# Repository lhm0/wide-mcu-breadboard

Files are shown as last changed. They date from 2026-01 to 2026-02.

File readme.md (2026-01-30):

# Fixing Breadboards for Wide Microcontrollers – Pico & ESP32 Edition

### Update 30.01.2026: added 3mf files for Arduino nano. There is a version with colored red and black lines next to the power rails (Arduino nano board only).

### Update 27.01.2026: breadboard for Arduino nano added. 

### Update 27.01.2026: breadboard for 900 mil ESP32 added. Renamed the STL files in order to avoid confusion, added .jpg files which correspond to the .stl files. Added model guide, which presents all available versions.

### Update 25.01.2026: test_print.stl added. This is a quick print of the breadboard's main feature. If your printer can handle this, it can also print the full breadboard.

### Update 22.01.2026: more variants included (photos to come), nozzle size included in readme.md

This project provides a custom 3D-printed breadboard body designed to accommodate modern, wide microcontroller development boards such as the **Raspberry Pi Pico**, **ESP32 Dev Board**, and **Arduino nano**. The metal spring contacts from a standard commercial breadboard are removed and reused inside the new housing, giving you a full-size 63×5 contact area and two power rails — just like the real thing.

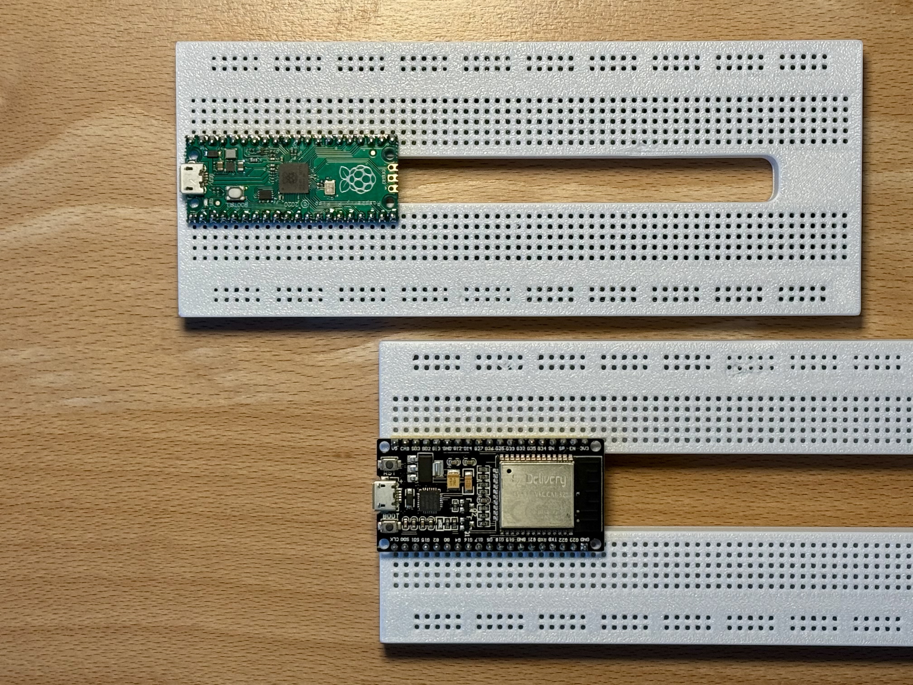
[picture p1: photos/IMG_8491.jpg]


## ✨ Why?

Many modern µC boards are too wide for typical solderless breadboards:

- With a **Raspberry Pi Pico**, only two holes per pin remain usable.
- With an **ESP32 Dev Board**, no holes remain at all — you need two breadboards side by side.

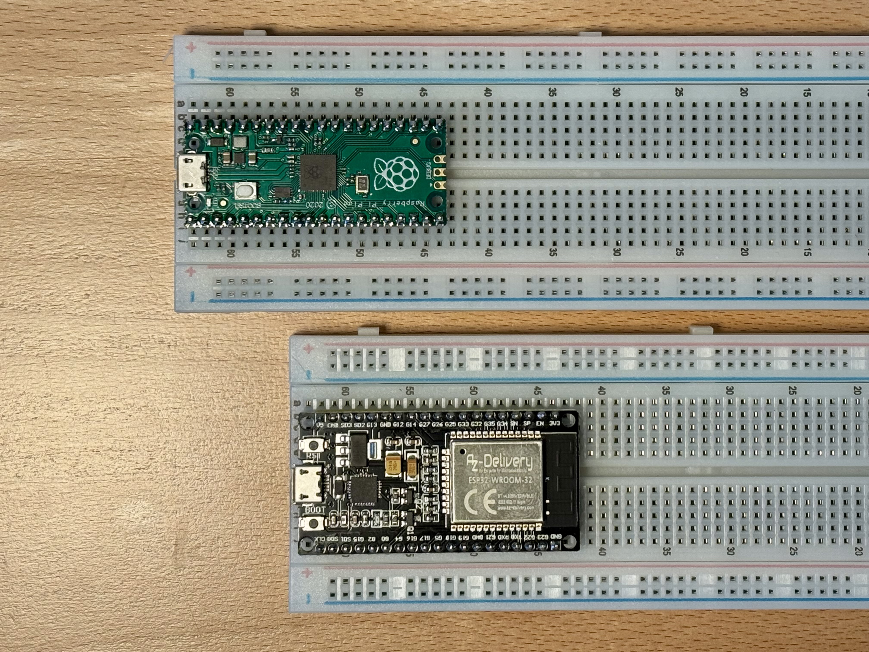
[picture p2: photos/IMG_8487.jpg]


With this custom breadboard, the microcontroller sits in the middle, leaving **four free holes per pin** for jumper wires and components — ideal for prototyping.

## 📦 Features

- Full 63×5 breadboard layout
- Two vertical power rails (left & right)
- Contact springs **recycled** from an existing breadboard
- Six variants:
  - **Pico version 1:** 7×2.54 mm pin spacing (17.78 mm)
  - **Pico version 2:** pin spacing split: 24 rows with 17.78 mm spacing (corresponds to RP pico), 39 rows with 7.62 mm spacing (correponds to DIL ICs)
  - **ESP32 version 1:** 10×2.54 mm pin spacing (25.40 mm)
  - **ESP32 version 2:** pin spacing split: 2 columns with 25.40 mm spacing, 3 columns with 7.62 mm spacing
  - **ESP32 version 3:** pin spacing split: 2 columns with 25.40 mm spacing, 2 columns with 7.62 mm spacing
  - **Arduino nano version 1:** 6*2.54 mm pin spacing (15.24 mm)
- Optional screw-mounted bottom plate
- Fully 3D-printable design (Fusion 360 source included)

## 📁 Included Files

This repository contains:

- /ESP32dev/          – Source CAD file, STL model, 3MF file for ESP32 development board
- /RaspberryPiPico/   – Source CAD file, STL model, 3MF file for Raspberry Pi Pico
- /photos/            – Build & assembly photos (for documentation)
- readme.md           - this file
- license.txt         - license

## 🖨 Printing Notes

- Material: **PLA** works well (ABS/ASA for heat resistance)
- Layer height: 0.2 mm recommended
- **nozzle diameter: 0.4 mm recommended**
- Infill: 50%
- Supports: Not required for main board
- Optional: Pause print to insert M2 nuts for screw mounting

Alternatively, the bottom plate may be **glued** instead of screwed.

## 🛠 Assembly Overview

1. Remove bottom adhesive tape from a commercial breadboard
2. Extract the metal spring contacts (keep power rails separate)
3. Insert contacts into the 3D-printed body
4. Insert power rails on both sides
5. Mount or glue the bottom plate
6. Plug in Pico or ESP32 and start prototyping!

## 📷 Photos & Documentation

See the Instructables article for full build documentation and photos:  
*link coming soon*

## 📝 Inspiration & Credits

The concept was inspired by the MAKE Advent Calendar project on Tinkercad:  
[MAKE ESP Breadboard](https://www.tinkercad.com/things/bsXsvygyo6F-make-esp-breadboard)
This version expands the idea to a **full-length 63-row breadboard** with **complete power rails**.

## 📜 License
Creative Commons Attribution-NonCommercial-ShareAlike 4.0 (CC BY-NC-SA 4.0)
see license.txt

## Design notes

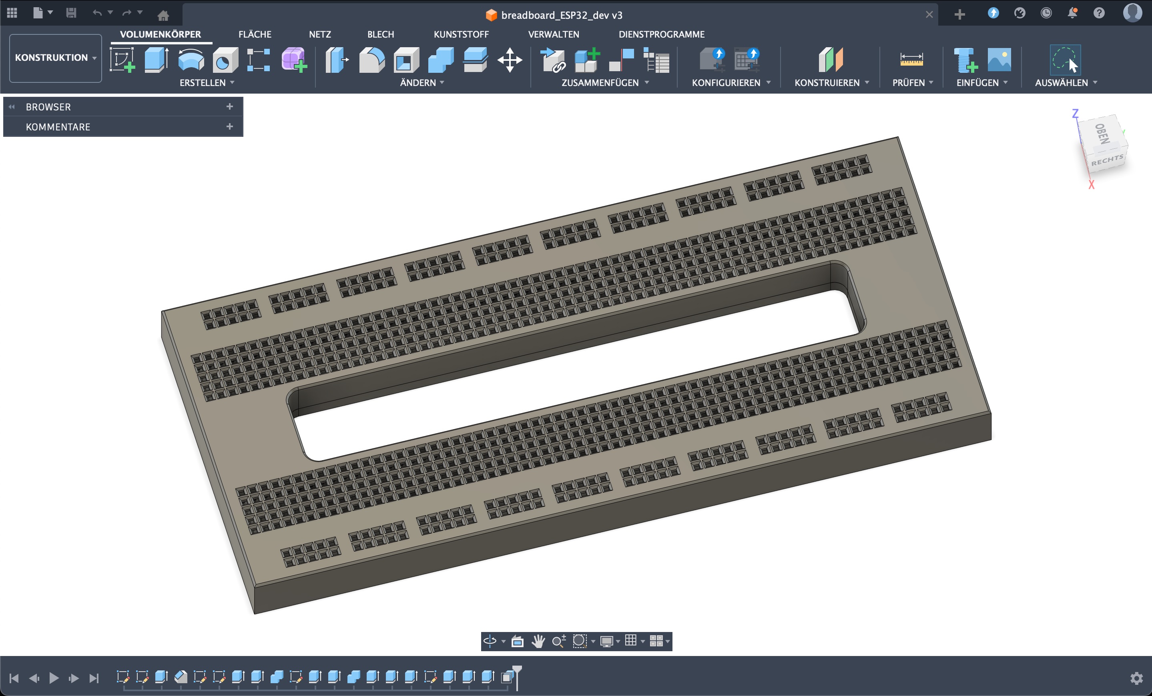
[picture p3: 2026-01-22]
photos/rendering_ESP32dev.jpg

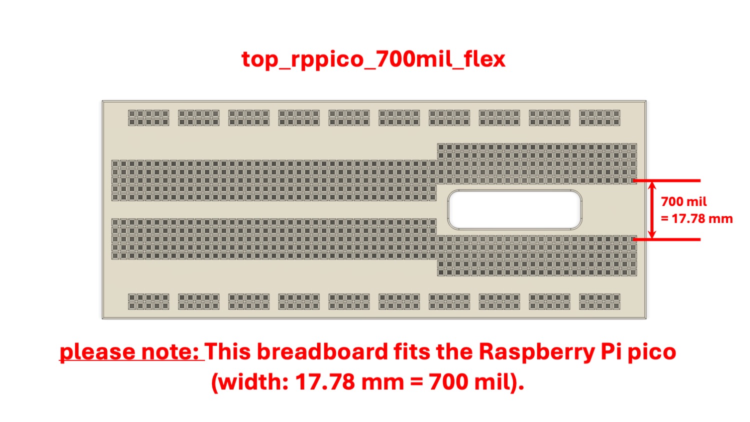
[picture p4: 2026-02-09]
photos/version6.jpeg

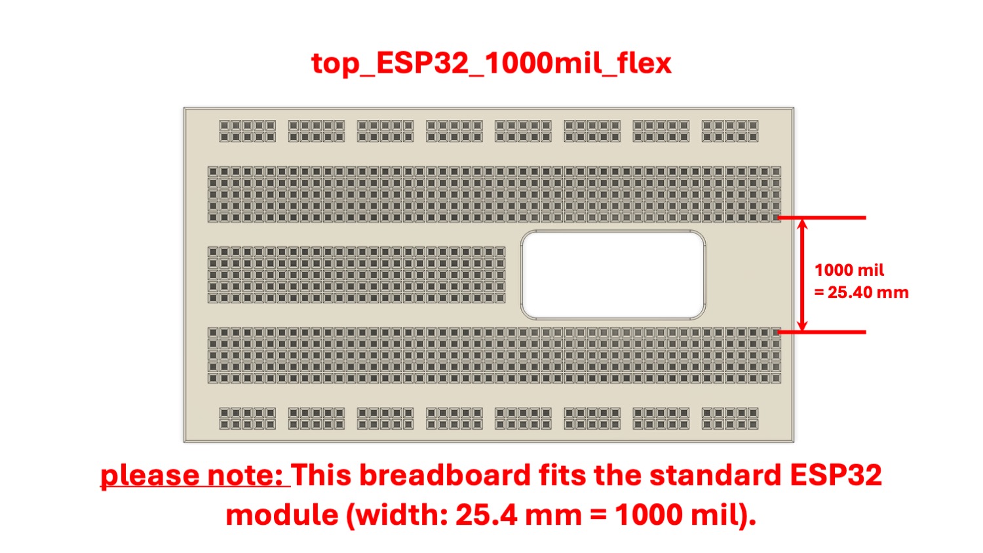
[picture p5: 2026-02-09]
photos/version2.jpeg

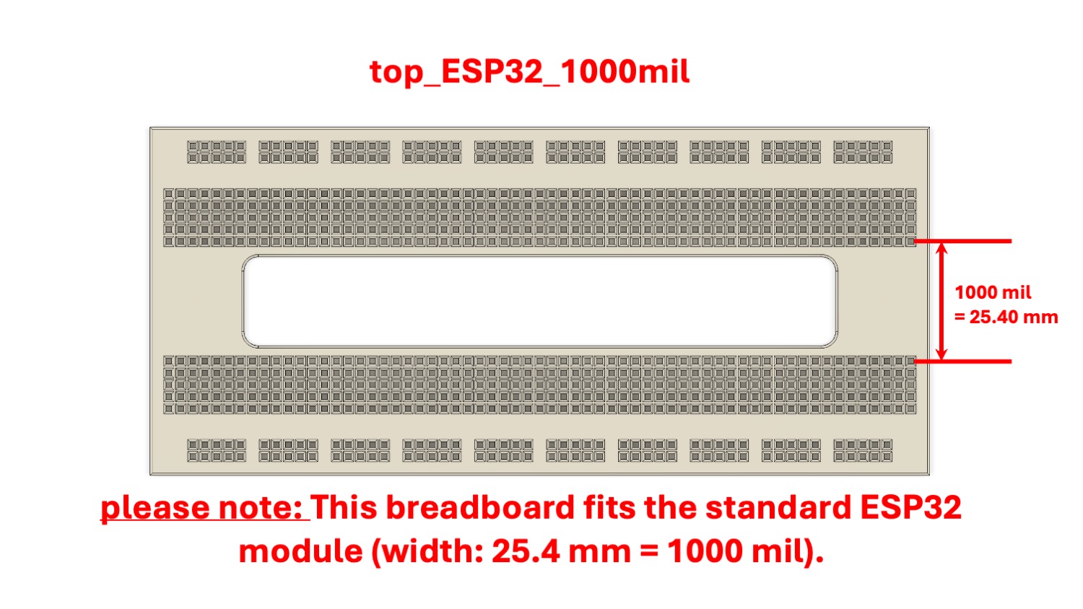
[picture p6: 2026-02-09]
photos/version1.jpeg

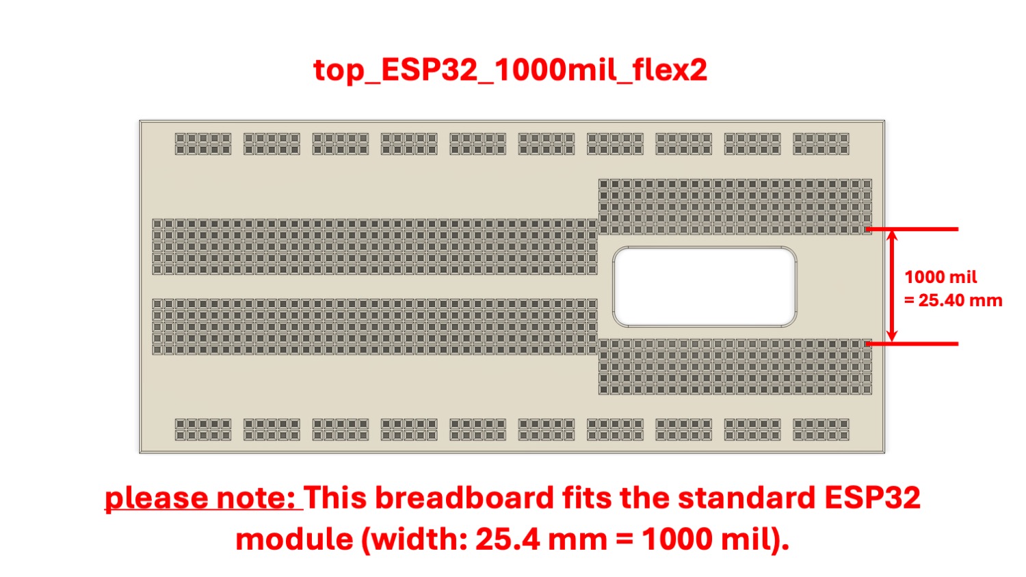
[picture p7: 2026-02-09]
photos/version3.jpeg

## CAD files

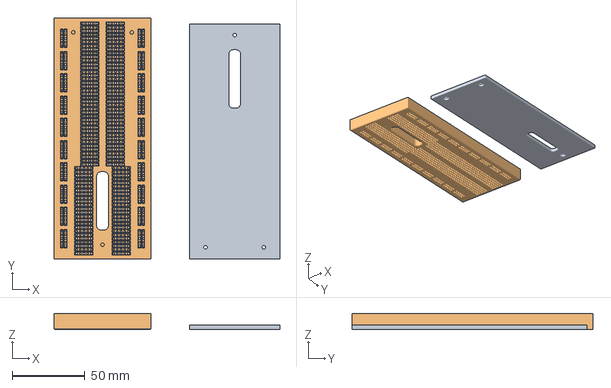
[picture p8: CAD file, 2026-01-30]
ArduinoNano/Arduino_nano_600mil_flex2.3mf
154.9 x 165.5 x 11.0 mm
bottom_Arduino_nano_600mil_flex2.stl
top_Arduino_nano_600mil_flex2.stl

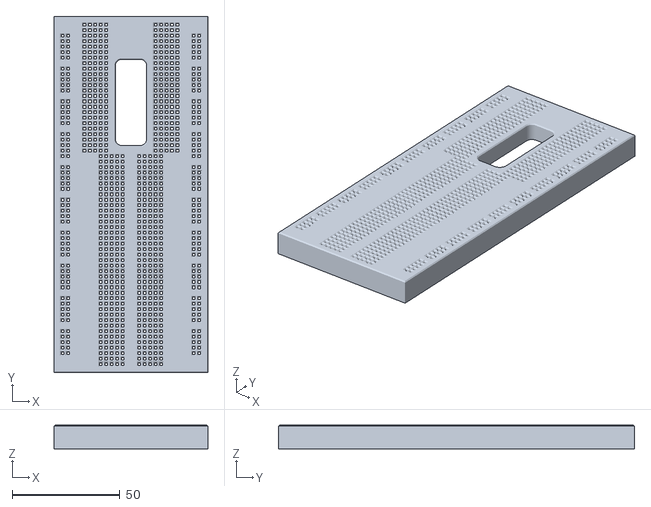
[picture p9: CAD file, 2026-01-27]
ESP32dev/top_ESP32_900mil_flex2.stl
71.5 x 165.5 x 11.0

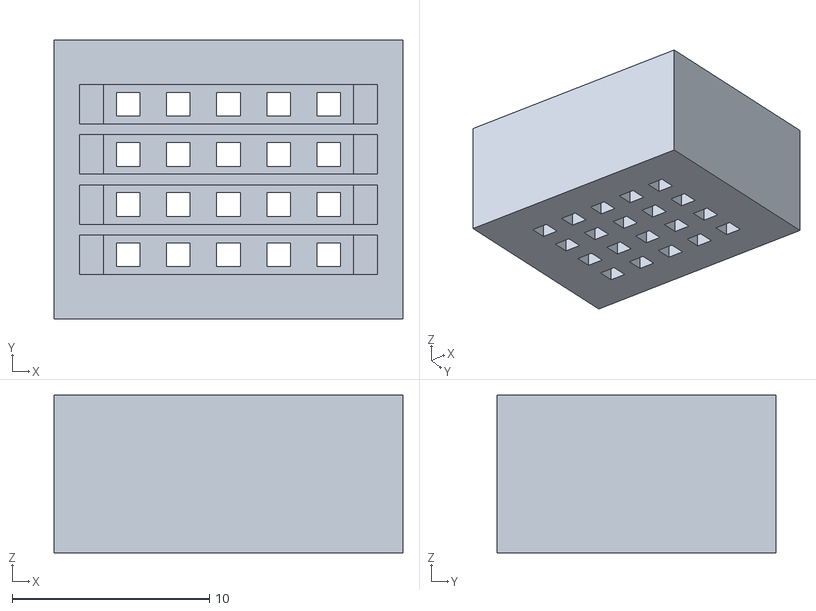
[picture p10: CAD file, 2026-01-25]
test_print/test_print.stl
17.7 x 14.2 x 8.00

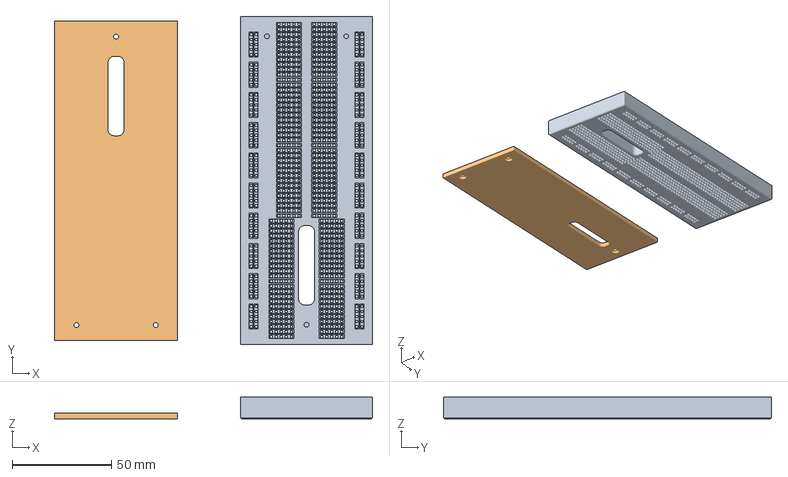
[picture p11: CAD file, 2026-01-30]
ArduinoNano/Arduino_nano_600mil_flex2_color.3mf
160.4 x 165.5 x 11.0 mm
top_Arsuino_nano_600mil_flex2_c
bottom_Arduino_nano_600mil_flex2.stl

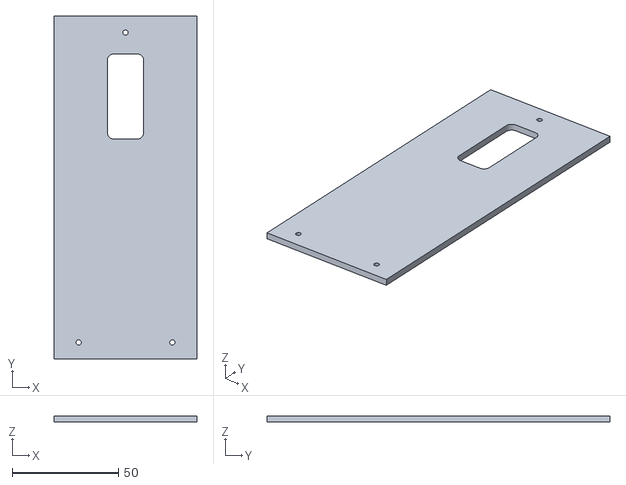
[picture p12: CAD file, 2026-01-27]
ESP32dev/bottom_ESP32_900mil_flex2.stl
67.1 x 161.1 x 3.00

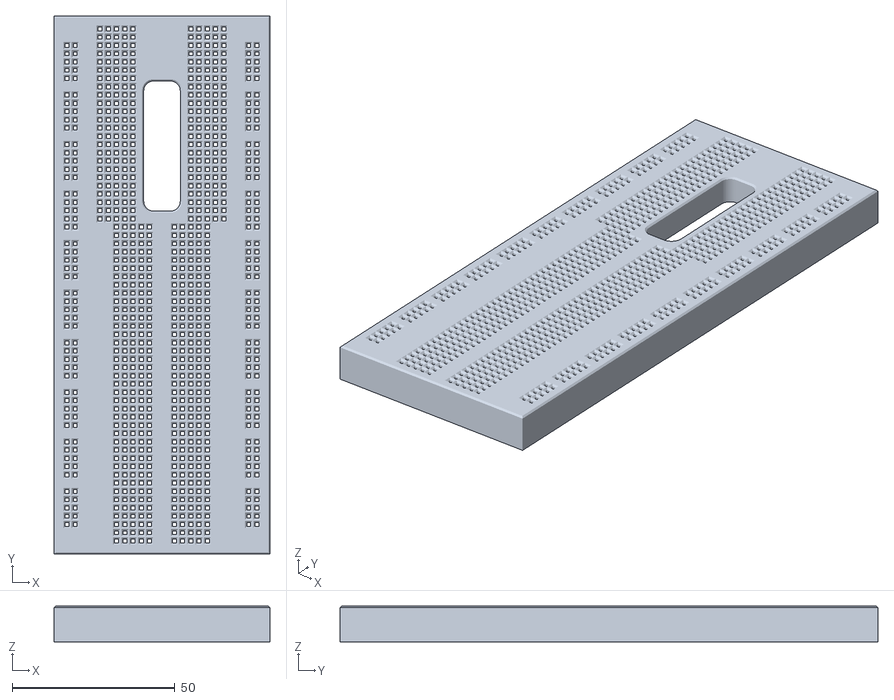
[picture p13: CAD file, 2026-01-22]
RaspberryPiPico/top_rppico_700mil_flex.stl
66.4 x 165.5 x 11.0

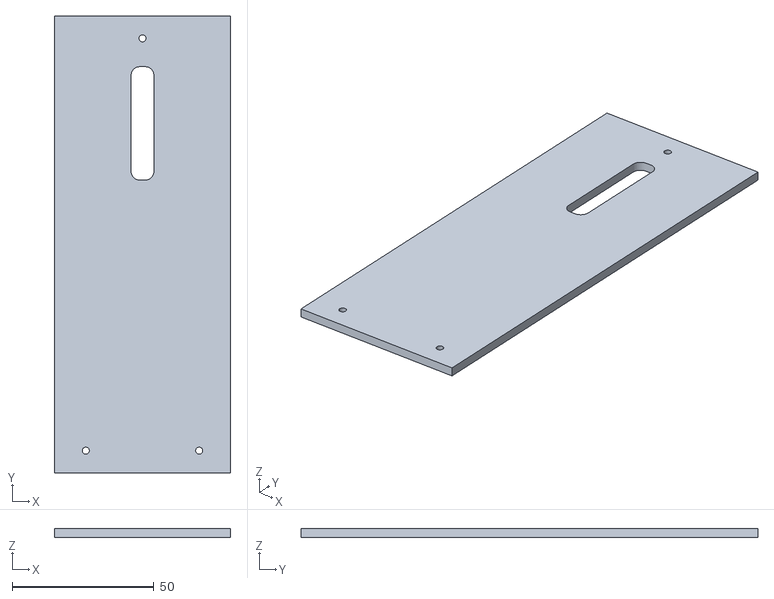
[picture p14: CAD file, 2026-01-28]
ArduinoNano/bottom_Arduino_nano_600mil_flex2.stl
62.1 x 161.1 x 3.00

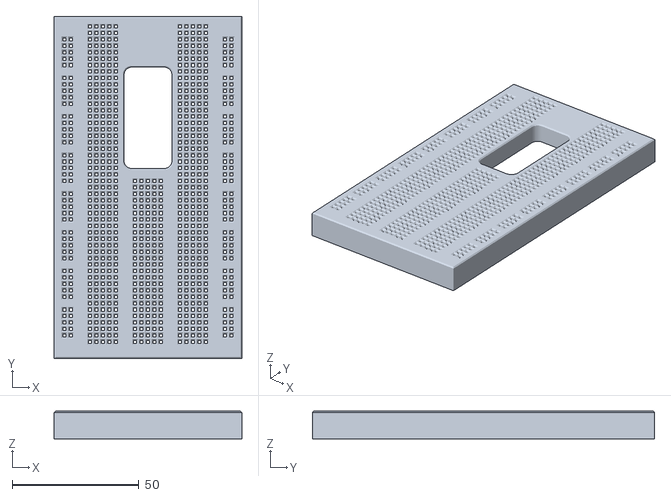
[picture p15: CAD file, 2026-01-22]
ESP32dev/top_ESP32_1000mil_flex.stl
74.0 x 135.0 x 11.0

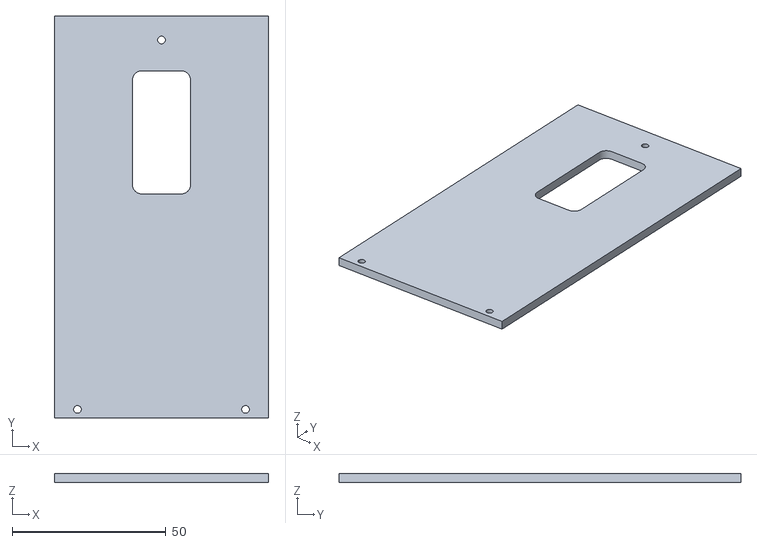
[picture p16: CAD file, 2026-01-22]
ESP32dev/bottom_ESP32_1000mil_flex.stl
69.6 x 130.6 x 3.00

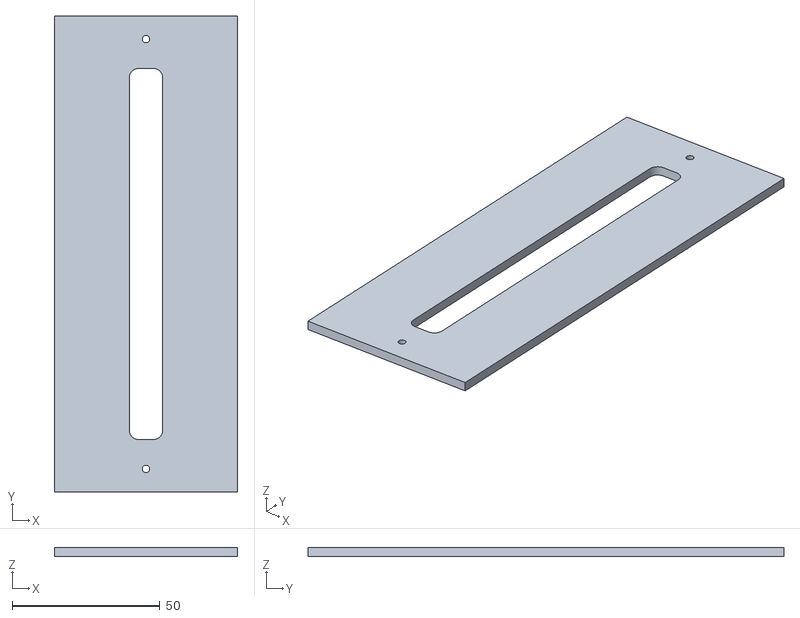
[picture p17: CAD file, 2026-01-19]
RaspberryPiPico/bottom_RPPico_700mil.stl
62.0 x 161.1 x 3.00

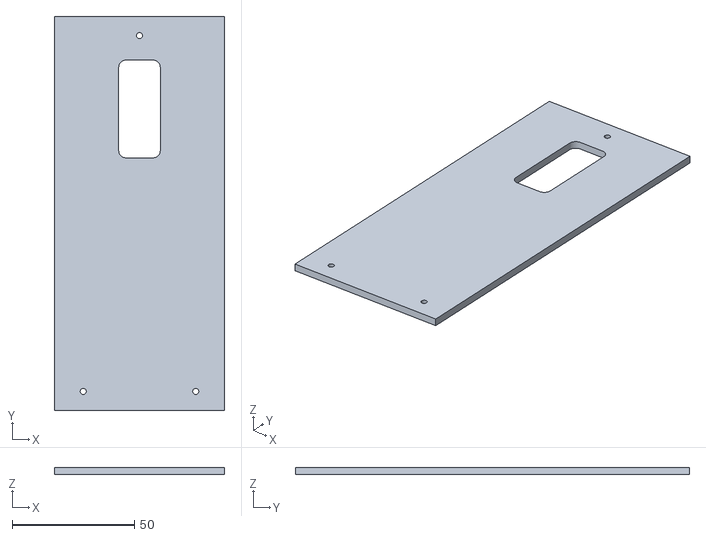
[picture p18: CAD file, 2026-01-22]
ESP32dev/bottom_ESP32_1000mil_flex2.stl
69.6 x 161.1 x 3.00

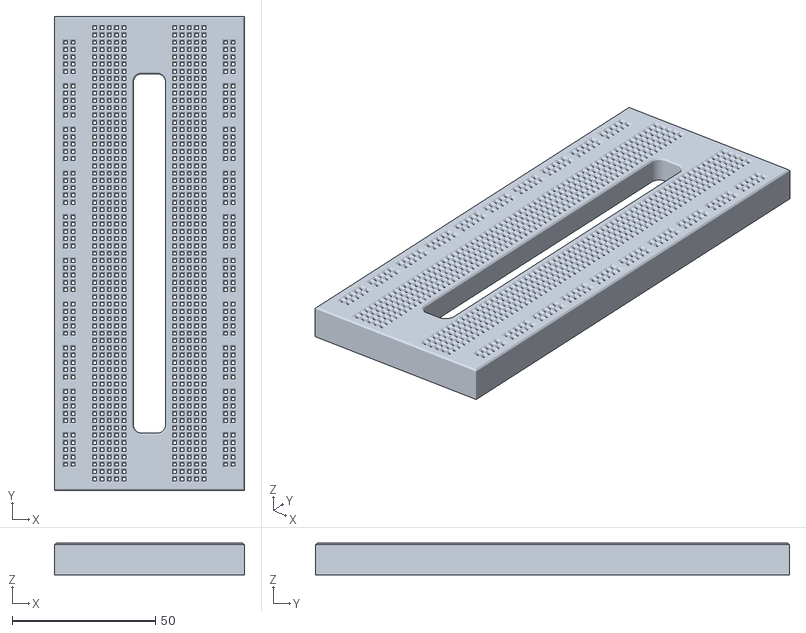
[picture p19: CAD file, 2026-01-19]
RaspberryPiPico/top_RPPico_700mil.stl
66.4 x 165.5 x 11.0

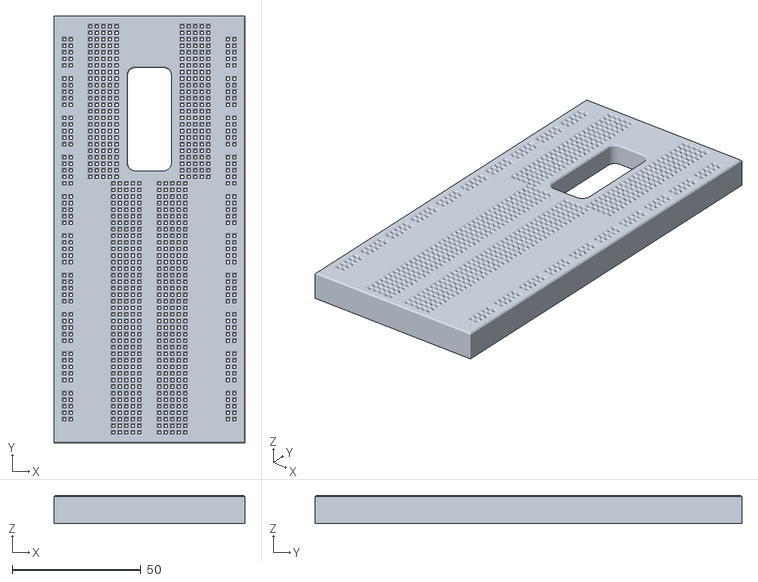
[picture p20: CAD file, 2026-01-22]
ESP32dev/top_ESP32_1000mil_flex2.stl
74.0 x 165.5 x 11.0

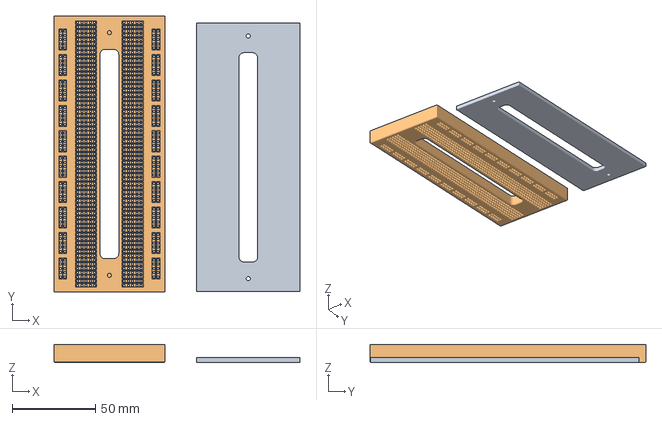
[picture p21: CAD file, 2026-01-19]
RaspberryPiPico/breadboard_rppico_700mil.3mf
147.5 x 165.5 x 11.0 mm
bottom_.stl
top_.stl

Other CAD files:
RaspberryPiPico/breadboard_rppico_700mil_flex.3mf
RaspberryPiPico/bottom_rppico_700mil_flex.stl
ArduinoNano/top_Arduino_nano_600mil_flex2.stl
ESP32dev/breadboard_ESP32_1000mil.3mf
ArduinoNano/breadboard_A_nano_600mil_flex2.f3d
ESP32dev/bottom_ESP32_1000mil.stl
ESP32dev/breadboard_ESP32_1000mil.f3d
ESP32dev/breadboard_ESP32_1000mil_flex.f3d
ESP32dev/breadboard_ESP32_1000mil_flex2.f3d
ESP32dev/breadboard_ESP32_900mil_flex2.f3d
ESP32dev/top_ESP32_1000mil.stl
RaspberryPiPico/breadboard_rppico_700mil.f3d
RaspberryPiPico/breadboard_rppico_700mil_flex.f3d
test_print/test_print.f3d

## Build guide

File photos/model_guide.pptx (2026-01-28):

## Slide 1

top_ESP32_1000mil

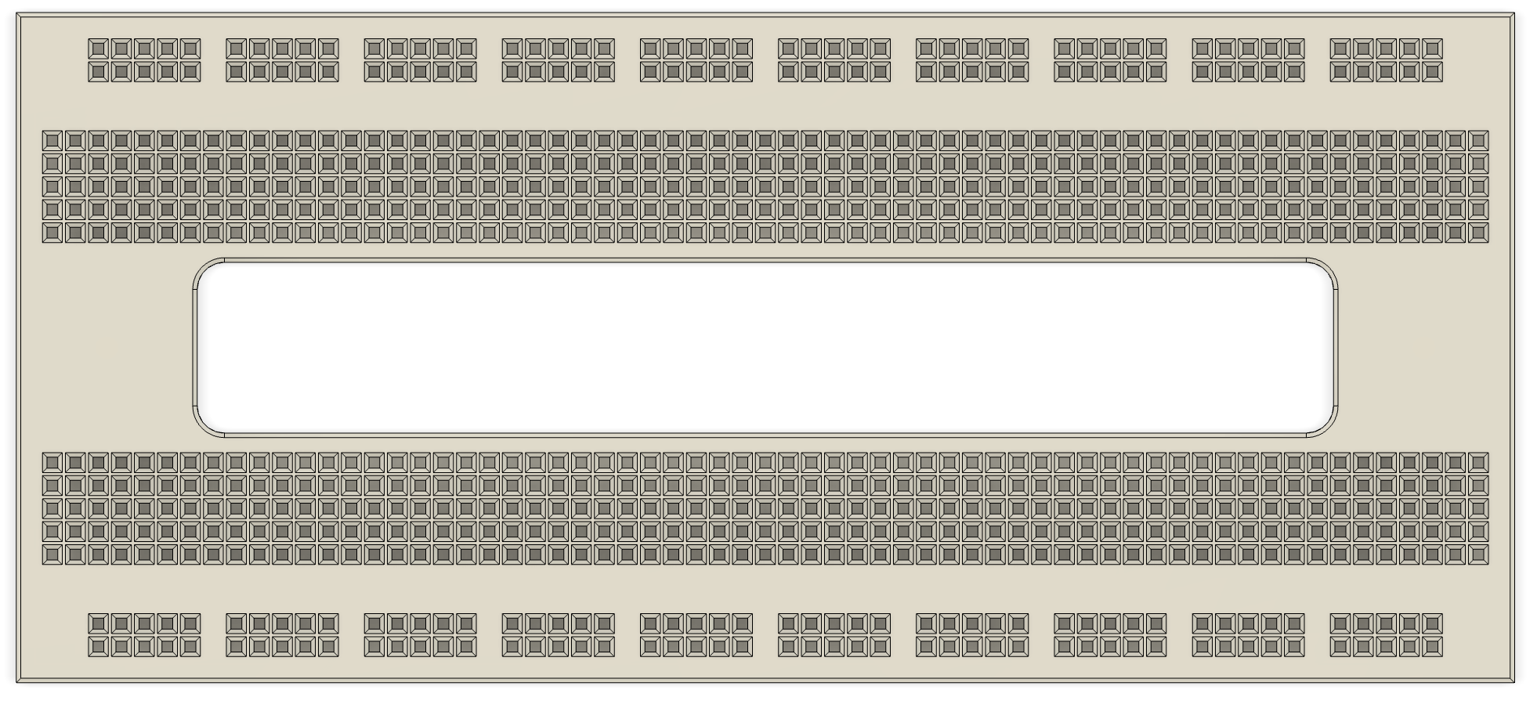
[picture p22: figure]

please note: This breadboard fits the standard ESP32 module (width: 25.4 mm = 1000 mil).

1000 mil
= 25.40 mm

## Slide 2

top_ESP32_1000mil_flex

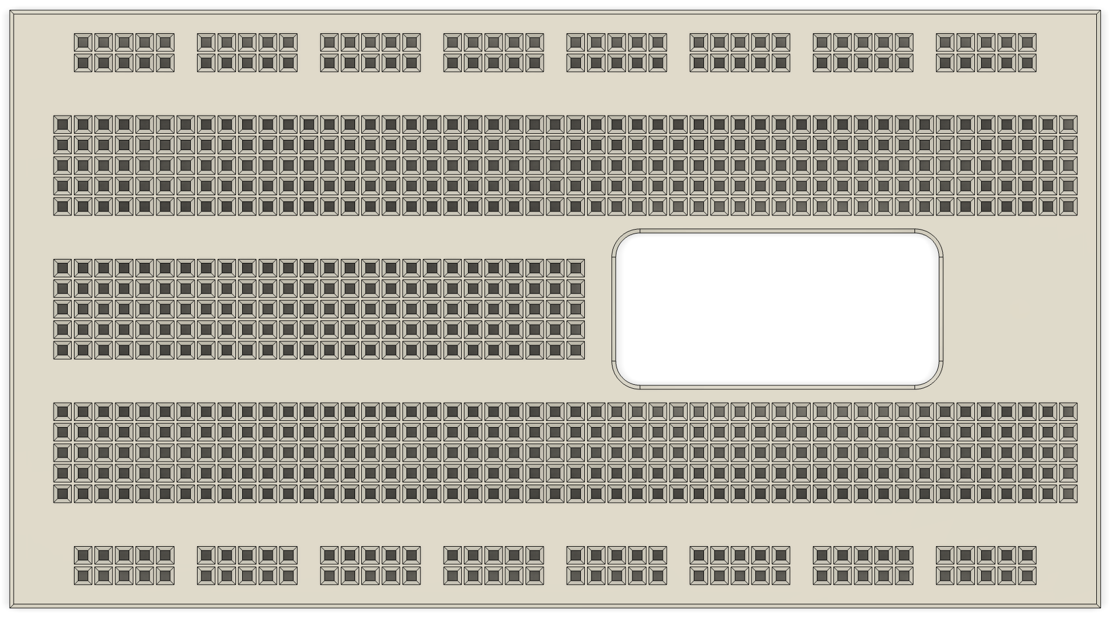
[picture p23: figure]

please note: This breadboard fits the standard ESP32 module (width: 25.4 mm = 1000 mil).

1000 mil
= 25.40 mm

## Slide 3

top_ESP32_1000mil_flex2

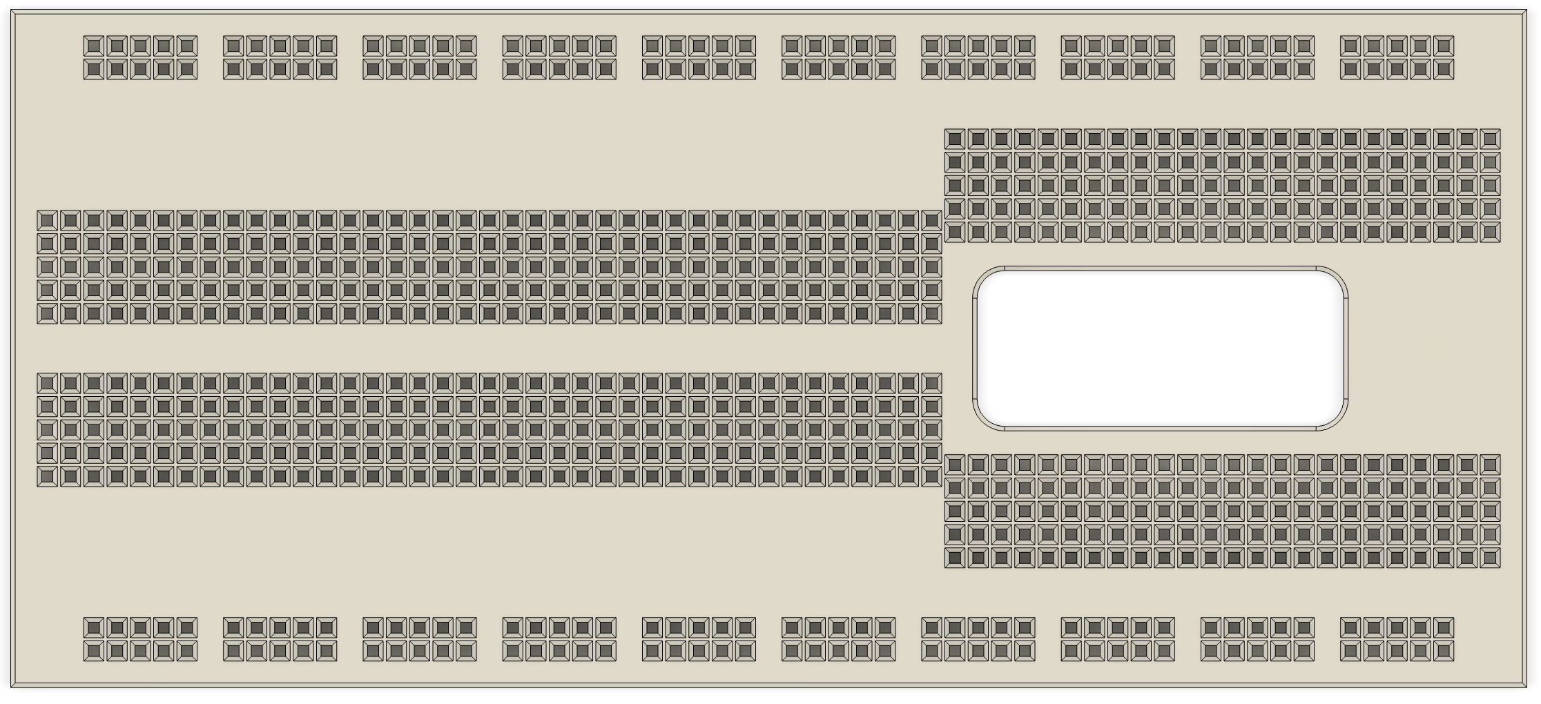
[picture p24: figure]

please note: This breadboard fits the standard ESP32 module (width: 25.4 mm = 1000 mil).

1000 mil
= 25.40 mm

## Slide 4

top_ESP32_900mil_flex2

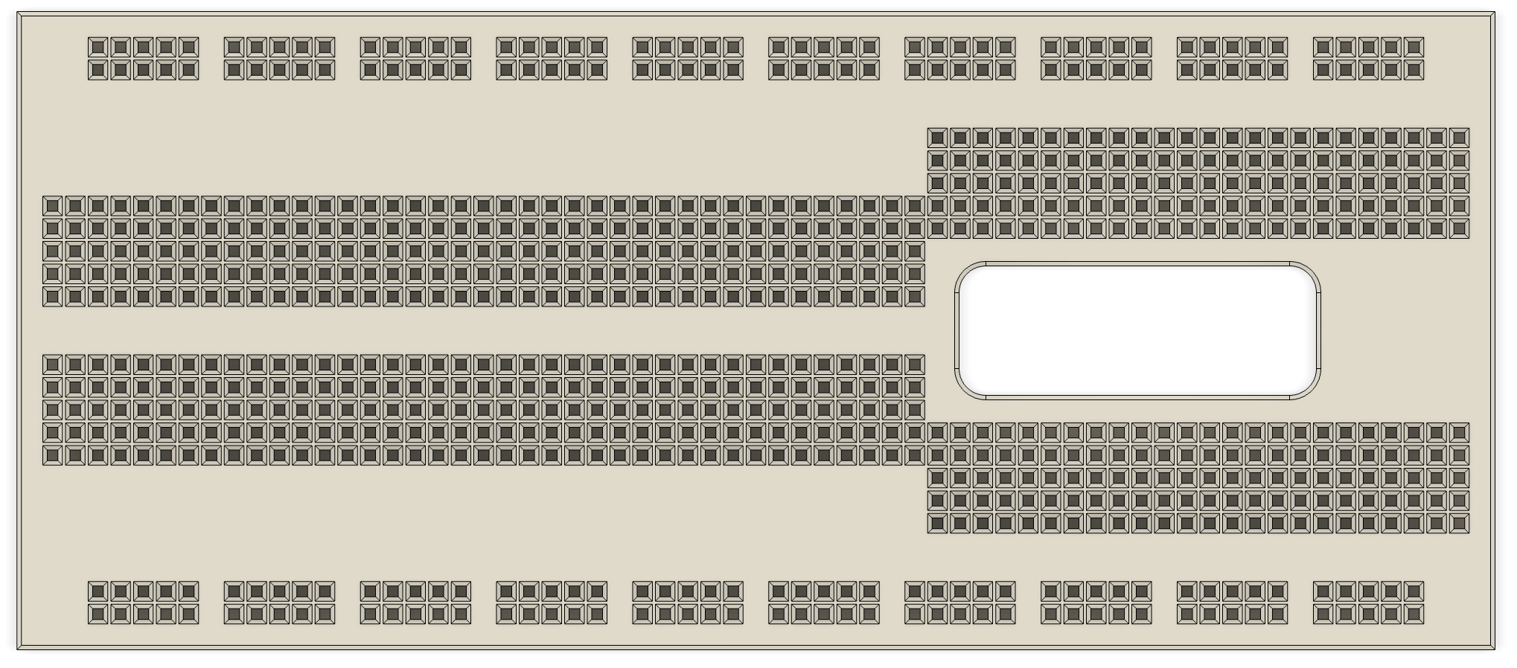
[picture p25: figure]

please note: this breadboard fits a narrow version of
the ESP32 module. Use the 1000 mil files for standard width

900 mil
= 22.86 mm

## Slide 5

top_RPPico_700mil

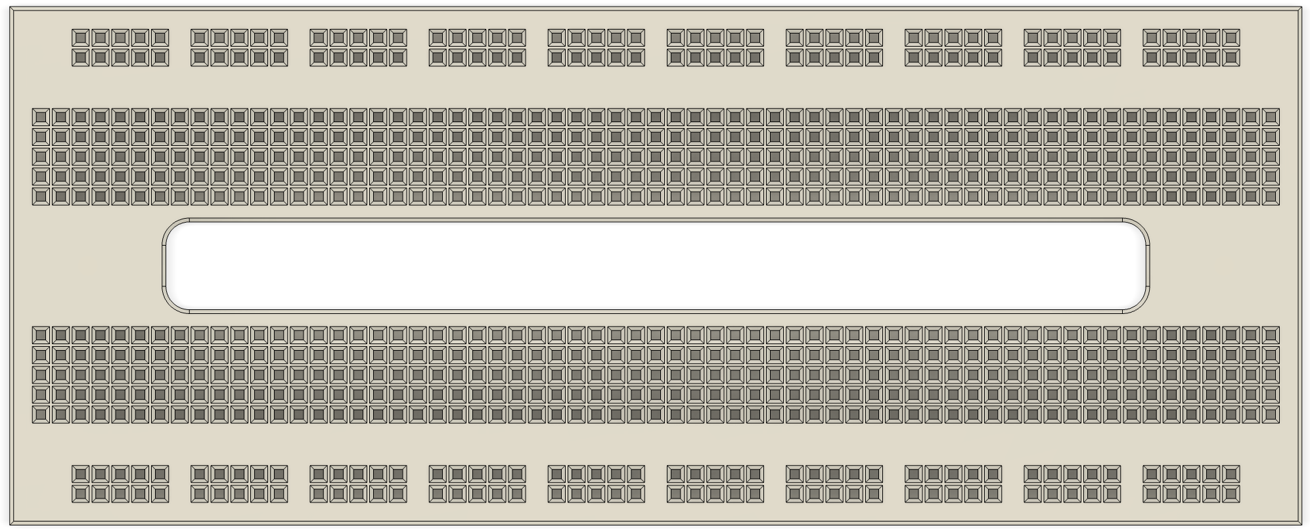
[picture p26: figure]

please note: This breadboard fits the Raspberry Pi pico (width: 17.78 mm = 700 mil).

700 mil
= 17.78 mm

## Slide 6

top_rppico_700mil_flex

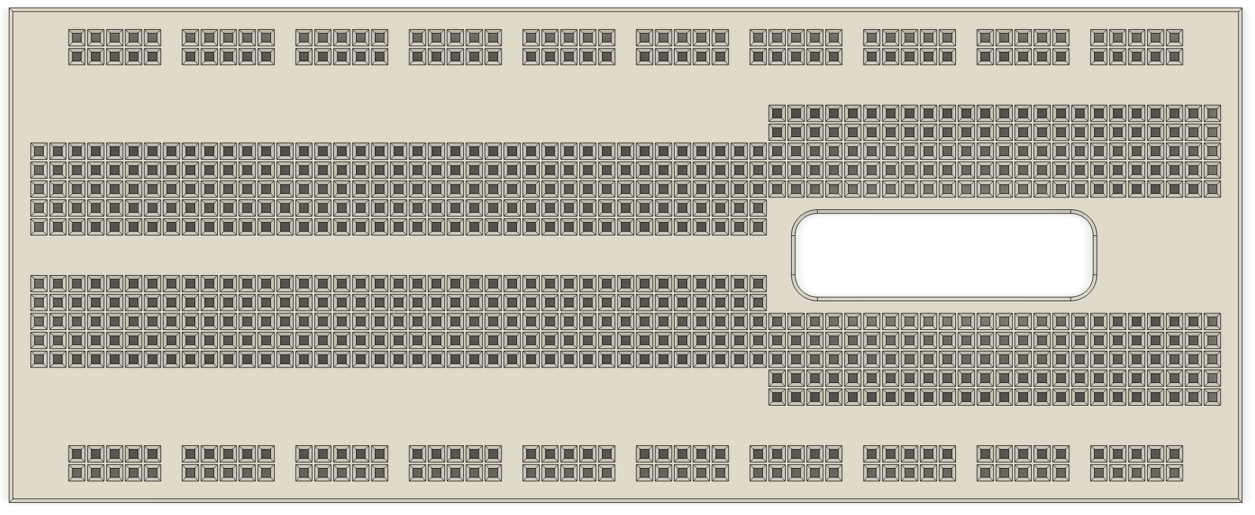
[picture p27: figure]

please note: This breadboard fits the Raspberry Pi pico (width: 17.78 mm = 700 mil).

700 mil
= 17.78 mm

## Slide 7

top_Arduino_nano_600mil_flex2

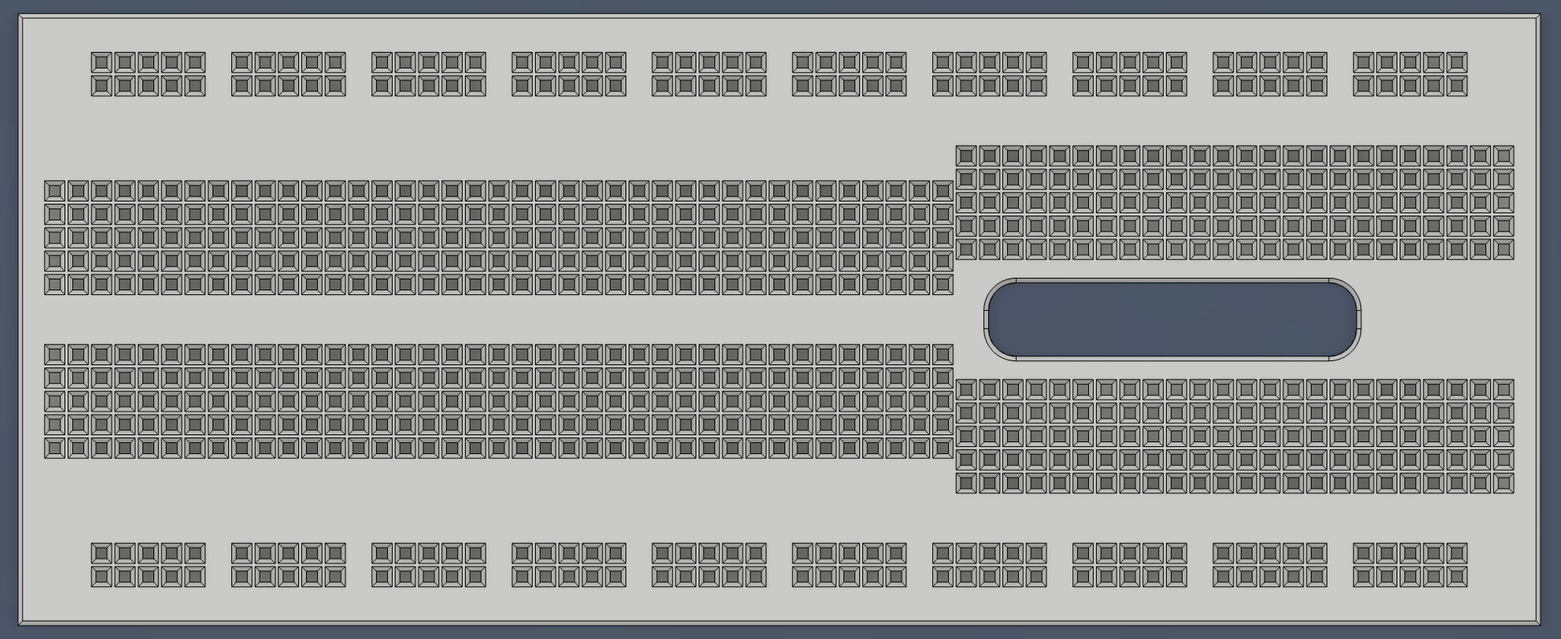
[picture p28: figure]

please note: This breadboard fits the Arduino nano
(width: 15.24 mm = 600 mil).

600 mil
= 15.24 mm

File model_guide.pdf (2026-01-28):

top_ESP32_1000mil

1000 mil
= 25.40 mm

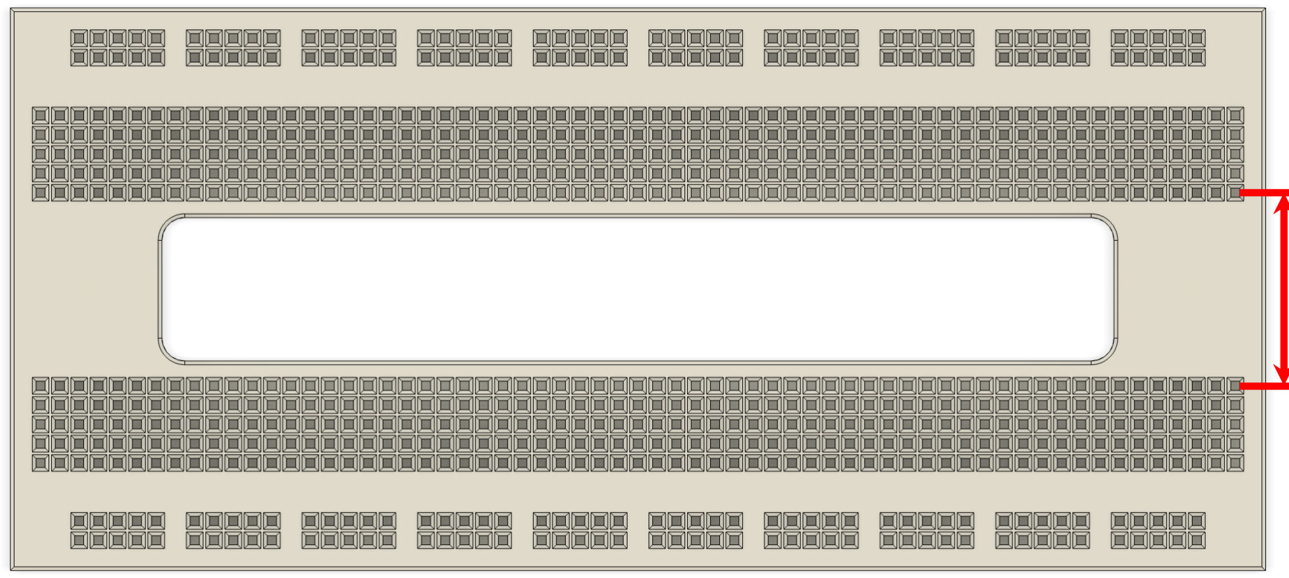
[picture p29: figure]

please note: This breadboard fits the standard ESP32 module (width: 25.4 mm = 1000 mil).

top_ESP32_1000mil_flex

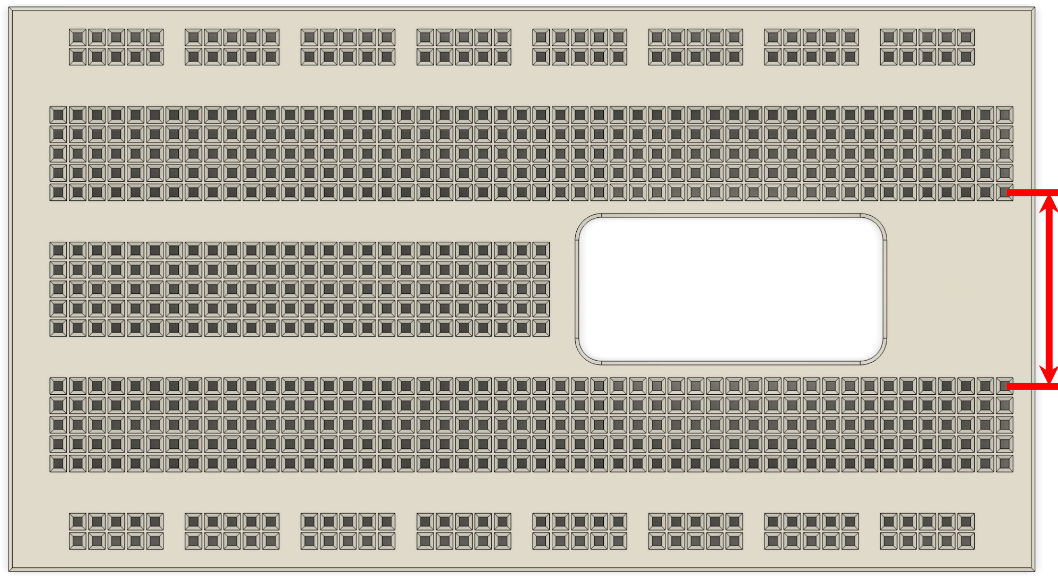
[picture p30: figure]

please note: This breadboard fits the standard ESP32 module (width: 25.4 mm = 1000 mil).

1000 mil
= 25.40 mm

1000 mil
= 25.40 mm

top_ESP32_1000mil_flex2

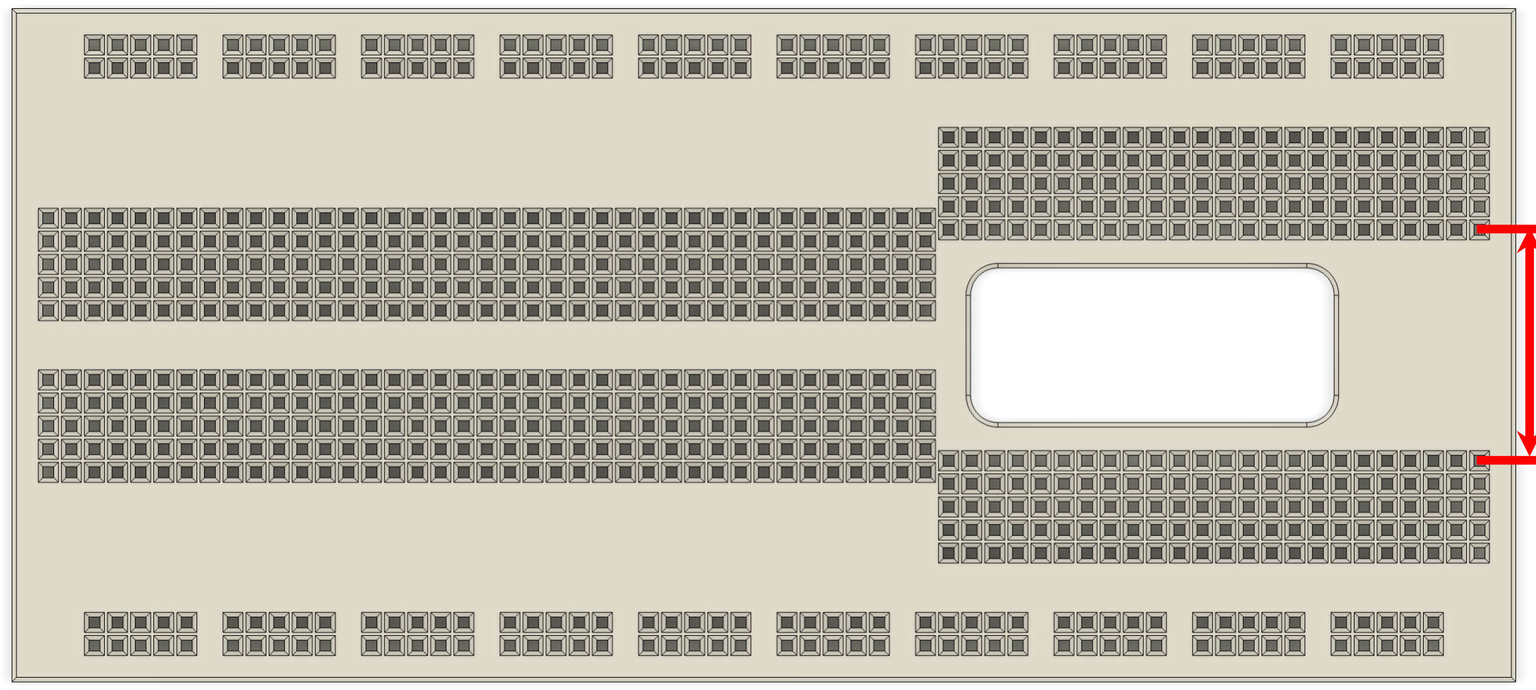
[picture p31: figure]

please note: This breadboard fits the standard ESP32 module (width: 25.4 mm = 1000 mil).

top_ESP32_900mil_flex2

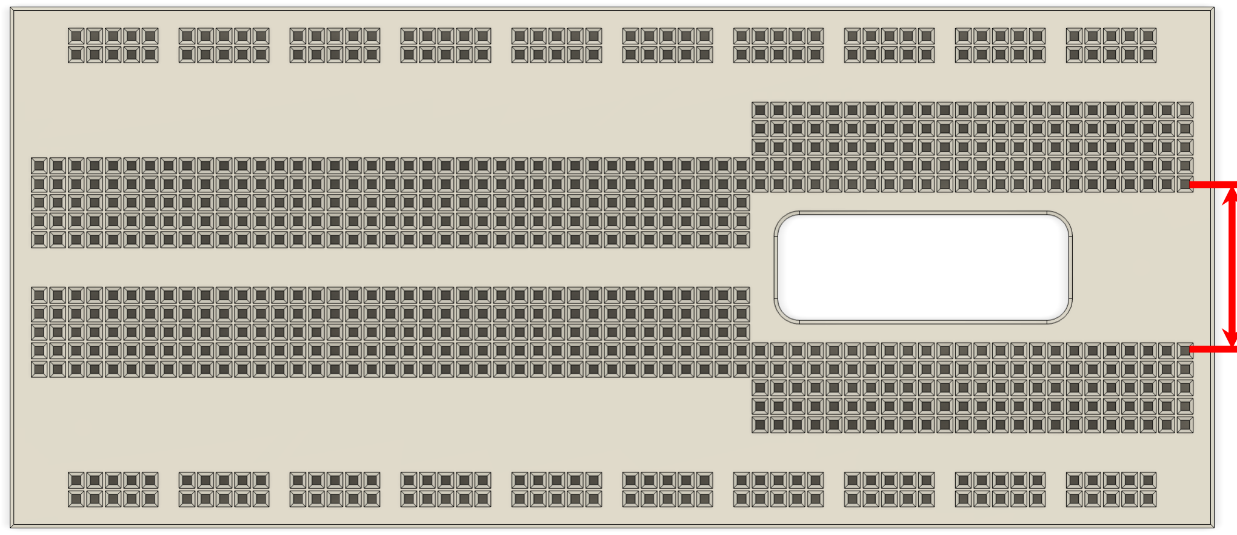
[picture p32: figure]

please note: this breadboard fits a narrow version of the ESP32 module. Use the 1000 mil files for standard width

900 mil
= 22.86 mm

top_RPPico_700mil

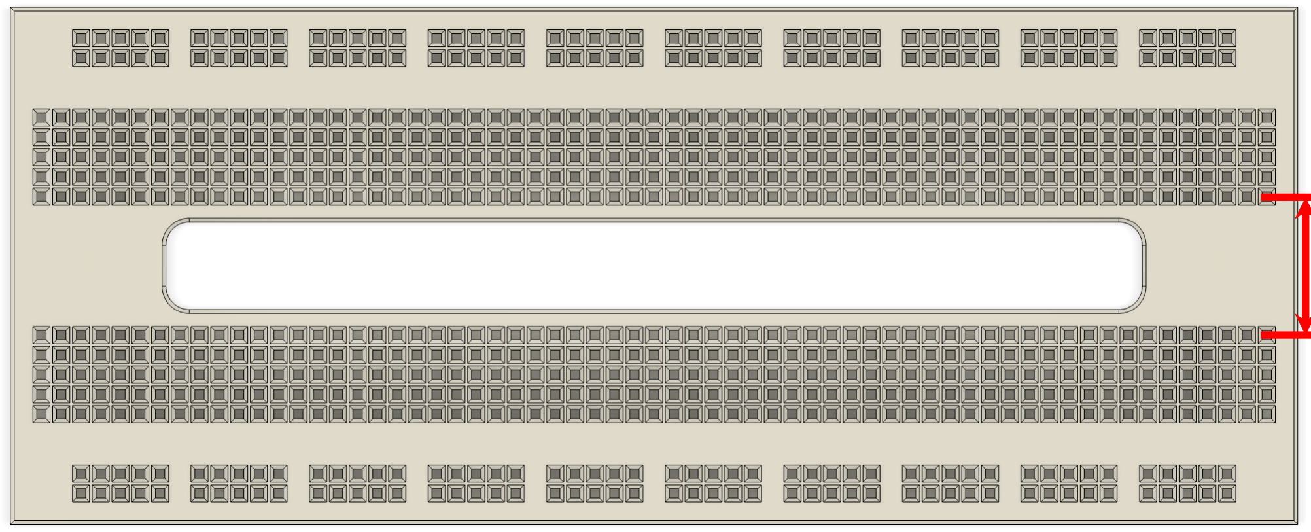
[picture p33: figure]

please note: This breadboard fits the Raspberry Pi pico (width: 17.78 mm = 700 mil).

700 mil
= 17.78 mm

top_rppico_700mil_flex

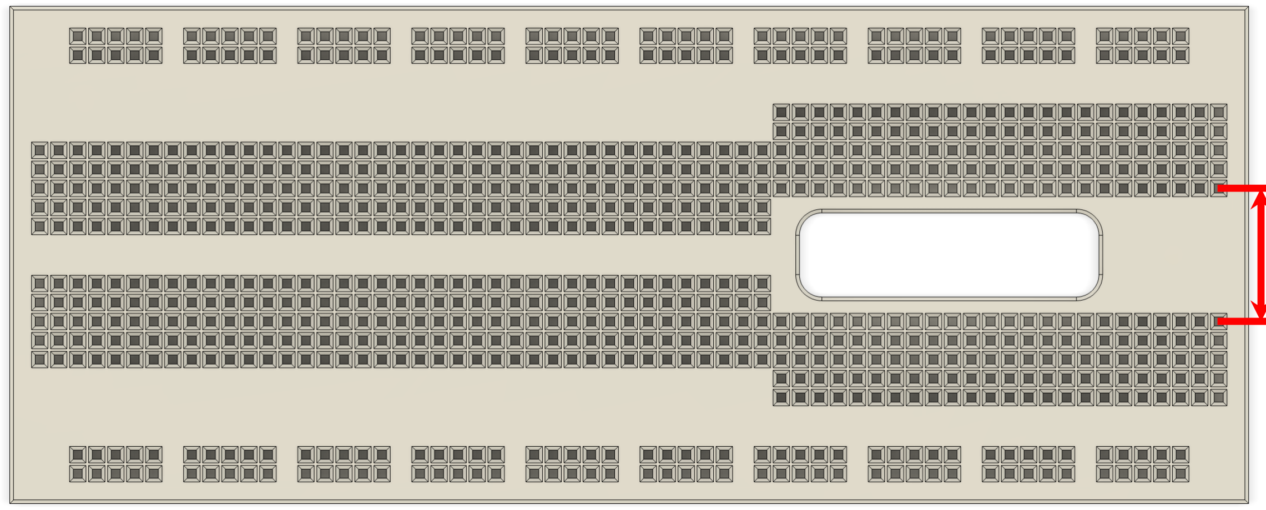
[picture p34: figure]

please note: This breadboard fits the Raspberry Pi pico (width: 17.78 mm = 700 mil).

700 mil
= 17.78 mm

600 mil
= 15.24 mm

top_Arduino_nano_600mil_flex2

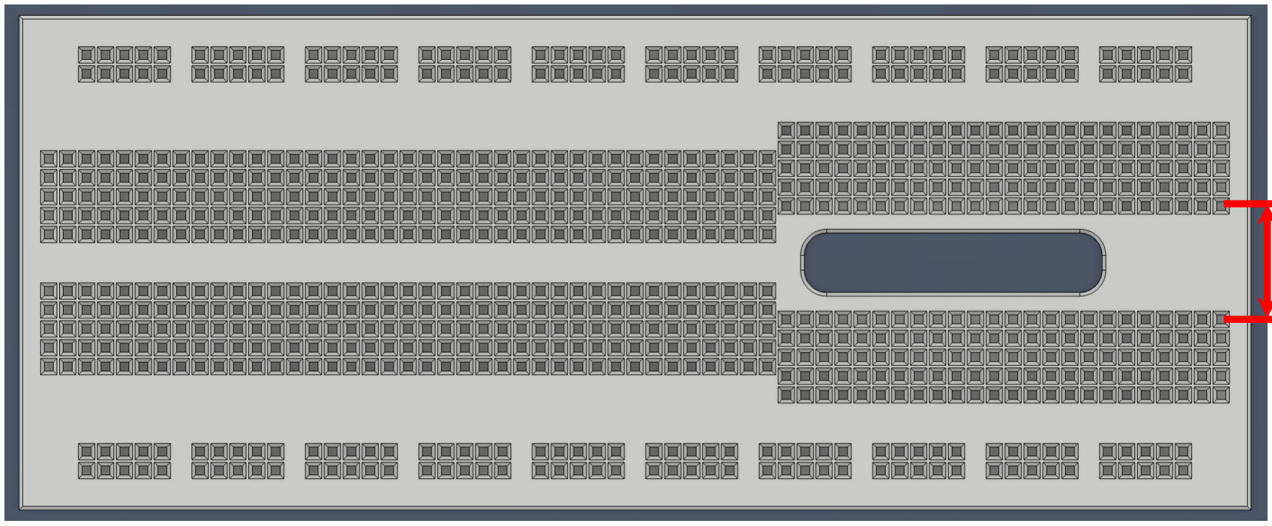
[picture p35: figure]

please note: This breadboard fits the Arduino nano (width: 15.24 mm = 600 mil).

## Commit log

2026-01-22 more variants added
    [bottom_ESP32_dev_flex2.stl, bottom_ESP32dev_flex.stl, bottom_rppico_flex.stl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]
2026-01-25 test_print.stl added
    [test_print.f3d, test_print.stl]
2026-01-27 900 mil ESP32 added. Consistent .stl file names. Model guide and jpg files added
    [bottom_ESP32_1000mil.stl, bottom_ESP32_1000mil_flex.stl, bottom_ESP32_1000mil_flex2.stl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]
2026-01-27 900 mil ESP32 bug fix
    [breadboard_ESP32_900mil_flex2.f3d, top_ESP32_900mil_flex2.stl]
2026-01-28 breadboard for Arduino nano added.
    [bottom_Arduino_nano_600mil_flex2.stl, breadboard_A_nano_600mil_flex2.f3d, top_Arduino_nano_600mil_flex2.stl]
2026-01-30 3mf files for Arduino nano added
    [Arduino_nano_600mil_flex2.3mf, Arduino_nano_600mil_flex2_color.3mf]
